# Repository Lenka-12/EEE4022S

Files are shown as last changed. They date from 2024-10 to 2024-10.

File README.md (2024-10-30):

# Audio Digitisation System 🎵



A high-performance audio digitization system built around the STM32F7 microcontroller, featuring dual Delta-Sigma ADCs (PCM1808 and ADAU1978) and an integrated ADC for comprehensive audio capture.

## 🎯 Overview

This project implements a complete audio digitization pipeline that captures audio data through multiple ADCs and transmits it to a PC for MATLAB-based analysis.

## 🔧 Hardware Components

### STM32F7 Nucleo Board
- Main processing unit
- Handles ADC interfacing and USB communication

### PCM1808 Delta-Sigma ADC ([Buy](https://www.aliexpress.com/item/32777376004.html))
- Stereo Audio ADC configuration
- Input: Bottom port MEMS microphone from DEVKIT-MEMS-001
- Signal conditioning via AD828 op-amp module ([AD828 Module Source](https://www.robotics.org.za/AD828A))
- I2S interface via SAI1 Block B
- 48 kHz sampling rate
- DMA circular mode operation

### Integrated ADC
- Input: Nucleo board pin A3
- Signal from top port MEMS microphone (DEVKIT-MEMS-001)
- Signal conditioning via BOB-09816 ([SparkFun BOB-09816](https://www.sparkfun.com/products/9816))
- Timer-triggered operation
- Circular DMA mode

### ADAU1978 Delta-Sigma ADC
- Integrated via [STEVAL-STWINMAV1](https://www.st.com/en/evaluation-tools/steval-stwinmav1.html) module
- TDM4 protocol through SAI1 Block A
- 24-bit resolution at 48 kHz
- DMA circular mode operation

> **Important Note**: When configuring SAI for TDM:
> - Clock strobing must be set to rising edge
> - Frame Synchro offset must be set before the First Bit

## 🔌 Communication

### USB Interface
- Protocol: USB Full Speed (FS) CDC
- Data transmission triggered by user button
- ADC activation controlled via Python script commands

## 💡 Status Indicators

| LED  | Function |
|---|---|
| LD1  | Integrated ADC active |
| LD2  | PCM1808 active |
| LD3  | ADAU1978 active |

## 🛠️ Hardware Sources

### Microphones
- [DEVKIT-MEMS-001](https://www.sameskydevices.com/product/audio/microphones/development-kits/devkit-mems-001)
  - Bottom port MEMS mic → PCM1808
  - Top port MEMS mic → Integrated ADC

### Signal Conditioning
- PCM1808: [AD828 Op-amp Module](https://www.robotics.org.za/AD828A)
- Integrated ADC: [BOB-09816](https://www.sparkfun.com/products/9816)

### ADC Modules
- [PCM1808 Stereo Delta-Sigma ADC](https://www.aliexpress.com/item/32777376004.html)
- [STEVAL-STWINMAV1](https://www.st.com/en/evaluation-tools/steval-stwinmav1.html) (ADAU1978)
- STM32F7 Integrated ADC

## 📝 PCB Documentation

The repository includes:
- STEVAL-STWINMAV1 module adapter designs
- Audio Digitisation Hardware based on PCM1862 (production pending)
- 
## 📊 Data Analysis

MATLAB scripts are provided for processing the captured audio data. See the `/Processing` directory for analysis tools.

## 🤝 Contributing

Contributions are welcome! Please read our [Contributing Guide](CONTRIBUTING.md) for details on our code of conduct and the process for submitting pull requests.

## 📄 License

This project is licensed under the MIT License - see the [LICENSE](LICENSE) file for details.

## ✨ Acknowledgments

- STMicroelectronics for the STEVAL-STWINMAV1 reference design
- Same Sky for DEVKIT-MEMS-001
- SparkFun Electronics for BOB-09816
- Contributors and testers

---
*For technical questions and support, please open an issue in the repository.*

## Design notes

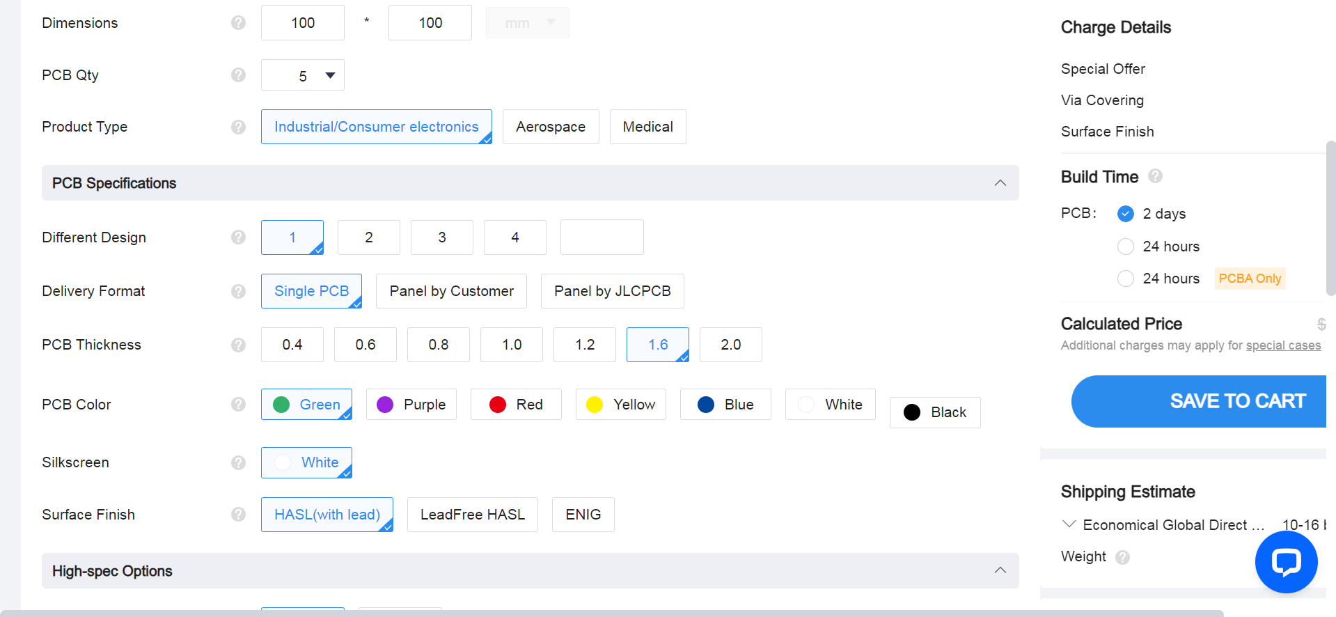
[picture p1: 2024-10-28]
PCB/Audio_Digitizer/Manufucturing/Images/Basic_PCB_Specs.png

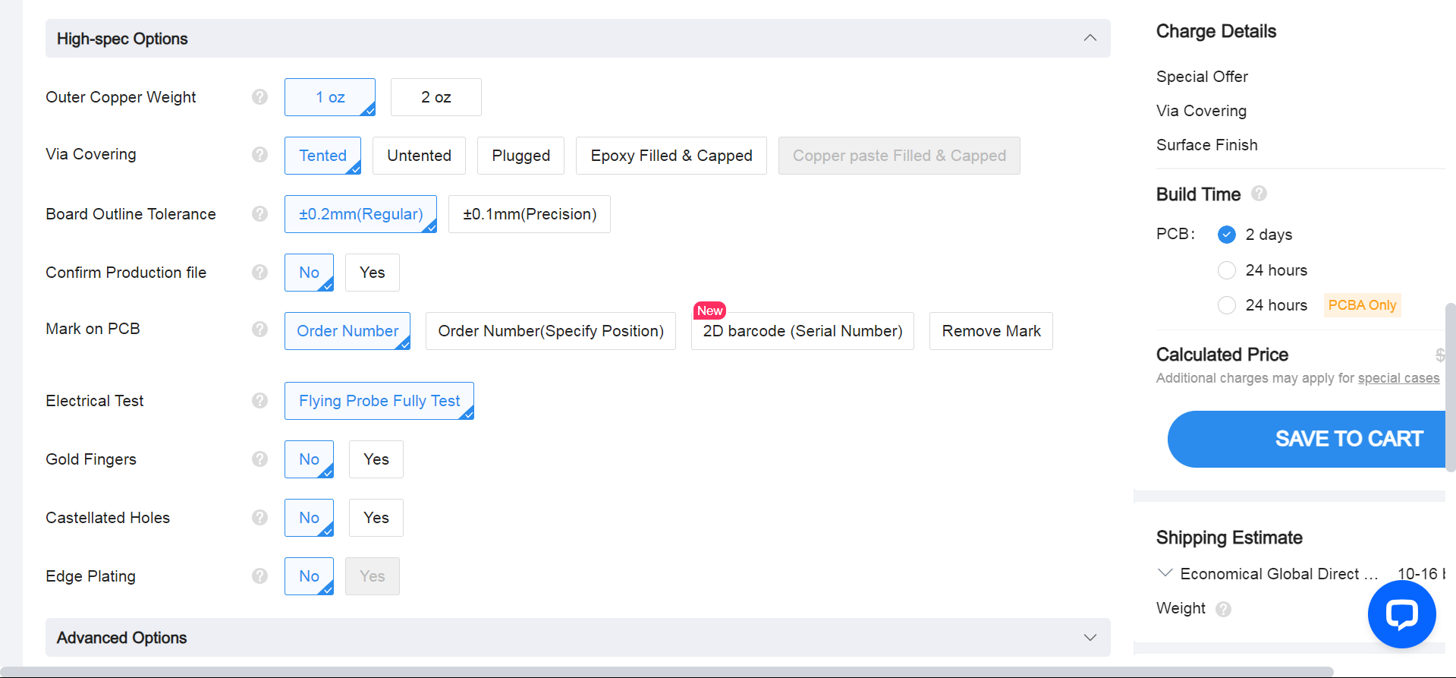
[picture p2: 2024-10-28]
PCB/Audio_Digitizer/Manufucturing/Images/PCB_High_Specs.png

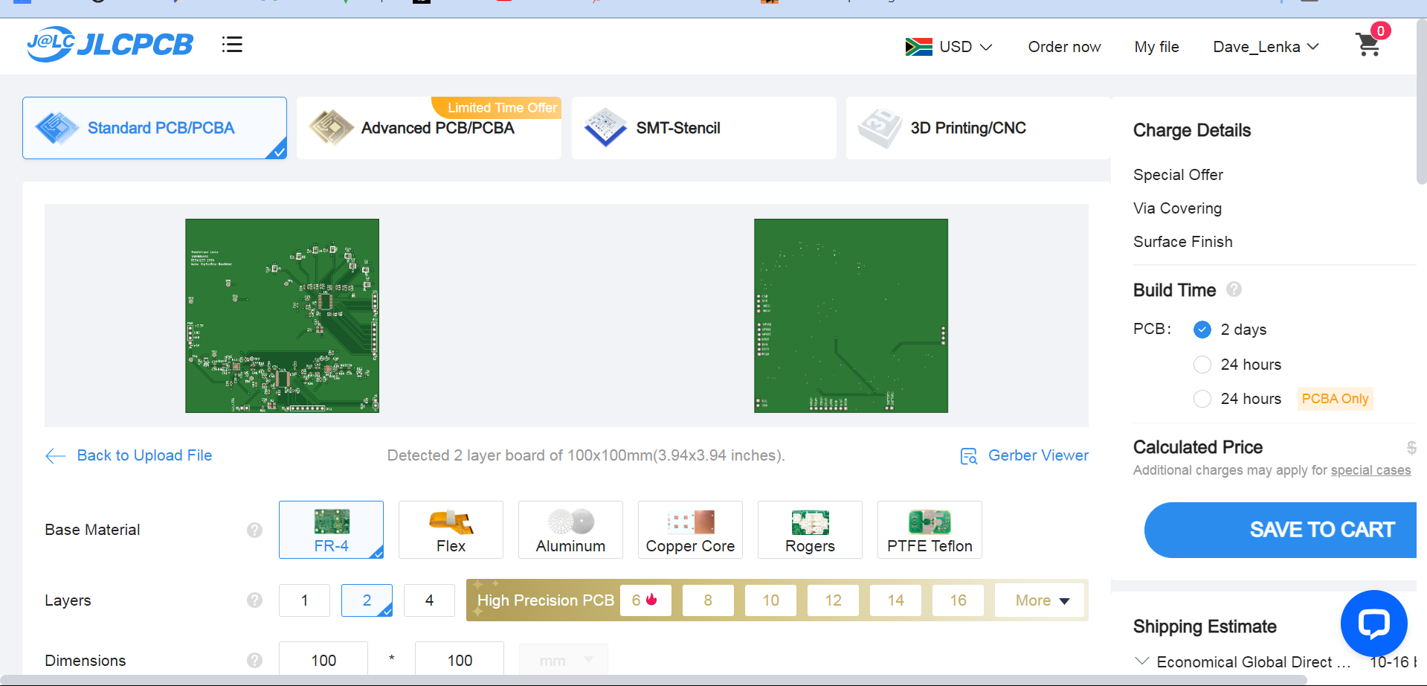
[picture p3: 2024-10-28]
PCB/Audio_Digitizer/Manufucturing/Images/PCB_Dimensions.png

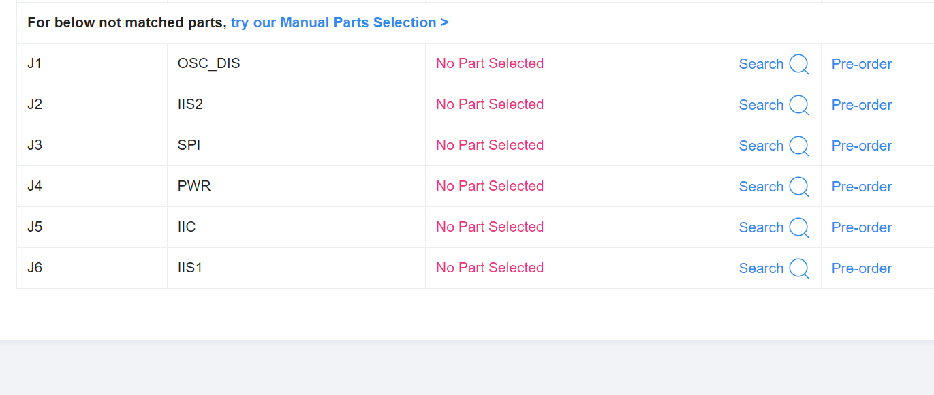
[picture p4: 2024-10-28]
PCB/Audio_Digitizer/Manufucturing/Images/Do_Not_Populate.png

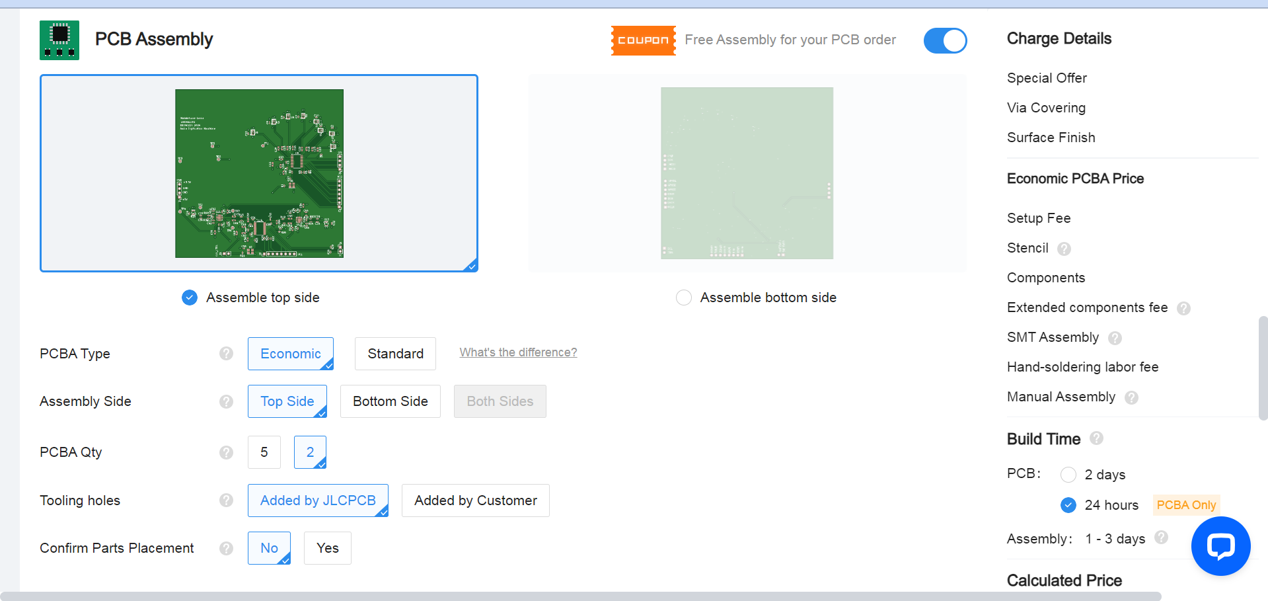
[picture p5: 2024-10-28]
PCB/Audio_Digitizer/Manufucturing/Images/PCBA_QTY.png

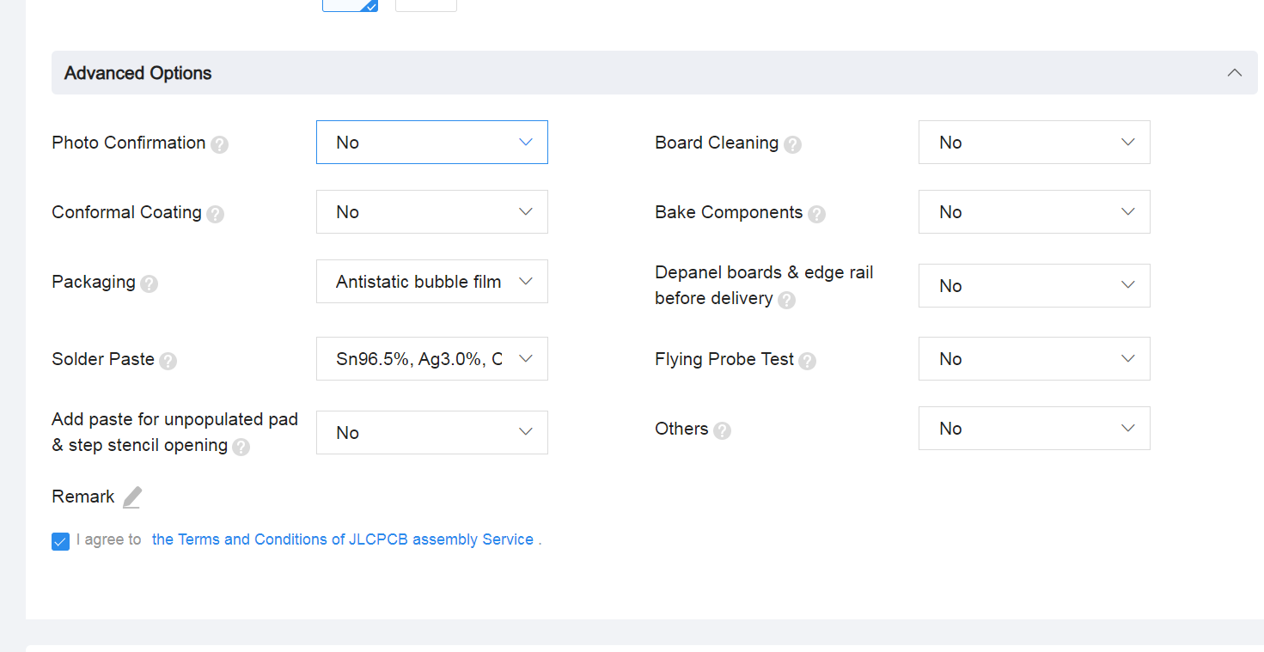
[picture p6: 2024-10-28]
PCB/Audio_Digitizer/Manufucturing/Images/PCBA_Advanced_Options.png

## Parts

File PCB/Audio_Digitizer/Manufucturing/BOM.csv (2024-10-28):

Reference | Value | Footprint | DNP | LCSC
C1,C2,C3,C4,C5,C6,C7,C9,C10,C12,C17,C24,C25,C26,C27,C28,C29,C30,C31,C32,C33,C56,C57,C58 | 100n | Capacitor_SMD:C_0402_1005Metric
C8,C11,C15,C16,C18,C19,C20,C21,C22,C23,C34,C35,C46,C47,C48,C52,C59,C60 | 10u | Capacitor_SMD:C_0603_1608Metric
C13,C14,C61,C62 | 2.2u | Capacitor_SMD:C_0603_1608Metric
C36,C37,C38,C39 | 4.7u | Capacitor_SMD:C_0402_1005Metric
C40,C43 | 100p | Capacitor_SMD:C_0402_1005Metric
C41,C42,C44,C45 | 47p | Capacitor_SMD:C_0402_1005Metric
C49,C51,C53,C55 | 220p | Capacitor_SMD:C_0402_1005Metric
C50,C54 | 6.8n | Capacitor_SMD:C_0603_1608Metric
J1 | OSC_DIS | Connector_PinHeader_2.54mm:PinHeader_1x02_P2.54mm_Vertical | DNP
J2 | IIS2 | Connector_PinHeader_2.54mm:PinHeader_1x07_P2.54mm_Vertical | DNP
J3 | SPI | Connector_PinHeader_2.54mm:PinHeader_1x04_P2.54mm_Vertical | DNP
J4 | PWR | Connector_PinHeader_2.54mm:PinHeader_1x04_P2.54mm_Vertical | DNP
J5 | IIC | Connector_PinHeader_2.54mm:PinHeader_1x02_P2.54mm_Vertical | DNP
J6 | IIS1 | Connector_PinHeader_2.54mm:PinHeader_1x08_P2.54mm_Vertical | DNP
R1,R5,R21,R25,R26 | 10k | Resistor_SMD:R_0402_1005Metric
R2,R3,R4,R6,R22,R23,R24,R27 | 22 | Resistor_SMD:R_0402_1005Metric
R7,R8 | 1k | Resistor_SMD:R_0603_1608Metric
R9,R10,R13,R14 | 1.2k | Resistor_SMD:R_0402_1005Metric
R11,R12,R15,R16 | 33k | Resistor_SMD:R_0402_1005Metric
R17,R18,R19,R20 | 47 | Resistor_SMD:R_0402_1005Metric
R28,R29 | 4.7k | Resistor_SMD:R_0402_1005Metric
TP1,TP2,TP3,TP4,TP5,TP6,TP7,TP8 | TestPoint | TestPoint:TestPoint_Pad_D1.5mm
U1,U2,U3,U4,U5,U6,U7,U8 | WMM7027ABSN0-4_TR | footprints:MIC-SMD_4P-L2.8-W1.9_MSM38A2718Z9BM3 |  | C2931972
U9,U14 | PCM1862DBTR | Package_SO:TSSOP-30_4.4x7.8mm_P0.5mm
U10,U12 | ZTS6216 | footprints:MIC-SMD_4P-L2.8-W1.9-P1.84-TL |  | C481302
U11,U13 | ADA4945-1ACPZ-R7 | Package_CSP:LFCSP-16-1EP_3x3mm_P0.5mm_EP1.6x1.6mm |  | C560261
X1,X2 | ASCO | Crystal:Crystal_SMD_3225-4Pin_3.2x2.5mm

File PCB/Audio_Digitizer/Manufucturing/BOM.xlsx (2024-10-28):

Designator | Comment | Footprint | JLCPCB Part #
C1,C2,C3,C4,C5,C6,C7,C9,C10,C12,C17,C24,C25,C26,C27,C28,C29,C30,C31,C32,C33,C56,C57,C58 | 100n | Capacitor_SMD:C_0402_1005Metric | C1525
C8,C11,C15,C16,C18,C19,C20,C21,C22,C23,C34,C35,C46,C47,C48,C52,C59,C60 | 10u | Capacitor_SMD:C_0603_1608Metric | C19702
C13,C14,C61,C62 | 2.2u | Capacitor_SMD:C_0603_1608Metric | C23630
C36,C37,C38,C39 | 4.7u | Capacitor_SMD:C_0402_1005Metric | C23733
C40,C43 | 100p | Capacitor_SMD:C_0402_1005Metric | C1546
C41,C42,C44,C45 | 47p | Capacitor_SMD:C_0402_1005Metric | C1567
C49,C51,C53,C55 | 220p | Capacitor_SMD:C_0402_1005Metric | C1530
C50,C54 | 6.8n | Capacitor_SMD:C_0603_1608Metric | C1631
J1 | OSC_DIS
J2 | IIS2
J3 | SPI
J4 | PWR
J5 | IIC
J6 | IIS1
R1,R5,R21,R25,R26 | 10k | Resistor_SMD:R_0402_1005Metric | C25744
R2,R3,R4,R6,R22,R23,R24,R27 | 22 | Resistor_SMD:R_0402_1005Metric | C25092
R7,R8 | 1k | Resistor_SMD:R_0603_1608Metric | C21190
R9,R10,R13,R14 | 1.2k | Resistor_SMD:R_0402_1005Metric | C25862
R11,R12,R15,R16 | 33k | Resistor_SMD:R_0402_1005Metric | C25779
R17,R18,R19,R20 | 47 | Resistor_SMD:R_0402_1005Metric | C25118
R28,R29 | 4.7k | Resistor_SMD:R_0402_1005Metric | C25900
U1,U2,U3,U4,U5,U6,U7,U8 | WMM7027ABSN0-4_TR | LGA-4(1.9x2.8) | C2931972
U9,U14 | PCM1862DBTR | TSSOP-30-4.4mm | C544647
U10,U12 | ZTS6216 | SMD-4P, 1.9x2.8mm | C481302
U11,U13 | ADA4945-1ACPZ-R7 | LFCSP-16(3x3) | C560261
X1,X2 | ASCO | SMD3225-4P | C2831388

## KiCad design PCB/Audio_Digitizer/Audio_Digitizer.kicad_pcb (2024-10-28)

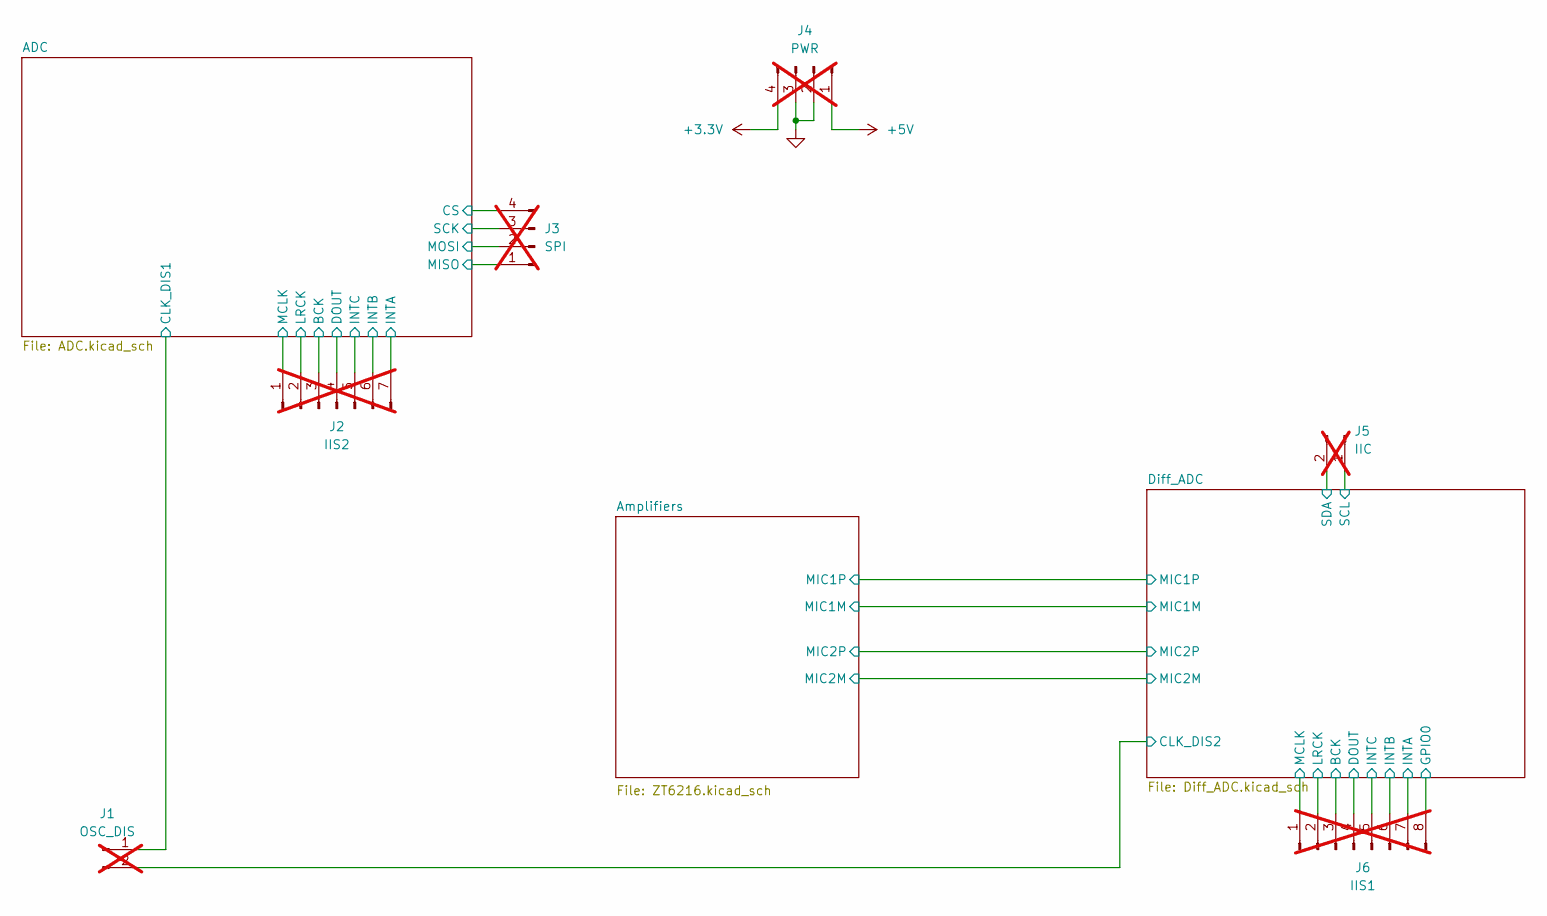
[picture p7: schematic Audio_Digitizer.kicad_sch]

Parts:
J1: OSC_DIS; PinHeader_1x02_P2.54mm_Vertical; not fitted
J2: IIS2; PinHeader_1x07_P2.54mm_Vertical; not fitted
J3: SPI; PinHeader_1x04_P2.54mm_Vertical; not fitted
J4: PWR; PinHeader_1x04_P2.54mm_Vertical; not fitted
J5: IIC; PinHeader_1x02_P2.54mm_Vertical; not fitted
J6: IIS1; PinHeader_1x08_P2.54mm_Vertical; not fitted

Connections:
+3.3V: J4.4; also elsewhere on the board
+5V: J4.1; also elsewhere on the board
/ADC/BCK: J2.3; also elsewhere on the board
/ADC/CLK_DIS1: J1.1; also elsewhere on the board
/ADC/CS: J3.4; also elsewhere on the board
/ADC/DOUT: J2.4; also elsewhere on the board
/ADC/INTA: J2.7; also elsewhere on the board
/ADC/INTB: J2.6; also elsewhere on the board
/ADC/INTC: J2.5; also elsewhere on the board
/ADC/LRCK: J2.2; also elsewhere on the board
/ADC/MCLK: J2.1; also elsewhere on the board
/ADC/MISO: J3.1; also elsewhere on the board
/ADC/MOSI: J3.2; also elsewhere on the board
/ADC/SCK: J3.3; also elsewhere on the board
/Diff_ADC/BCK: J6.3; also elsewhere on the board
/Diff_ADC/CLK_DIS2: J1.2; also elsewhere on the board
/Diff_ADC/DOUT: J6.4; also elsewhere on the board
/Diff_ADC/GPIO0: J6.8; also elsewhere on the board
/Diff_ADC/INTA: J6.7; also elsewhere on the board
/Diff_ADC/INTB: J6.6; also elsewhere on the board
/Diff_ADC/INTC: J6.5; also elsewhere on the board
/Diff_ADC/LRCK: J6.2; also elsewhere on the board
/Diff_ADC/MCLK: J6.1; also elsewhere on the board
/Diff_ADC/SCL: J5.1; also elsewhere on the board
/Diff_ADC/SDA: J5.2; also elsewhere on the board
GND: J4.2, J4.3; also elsewhere on the board

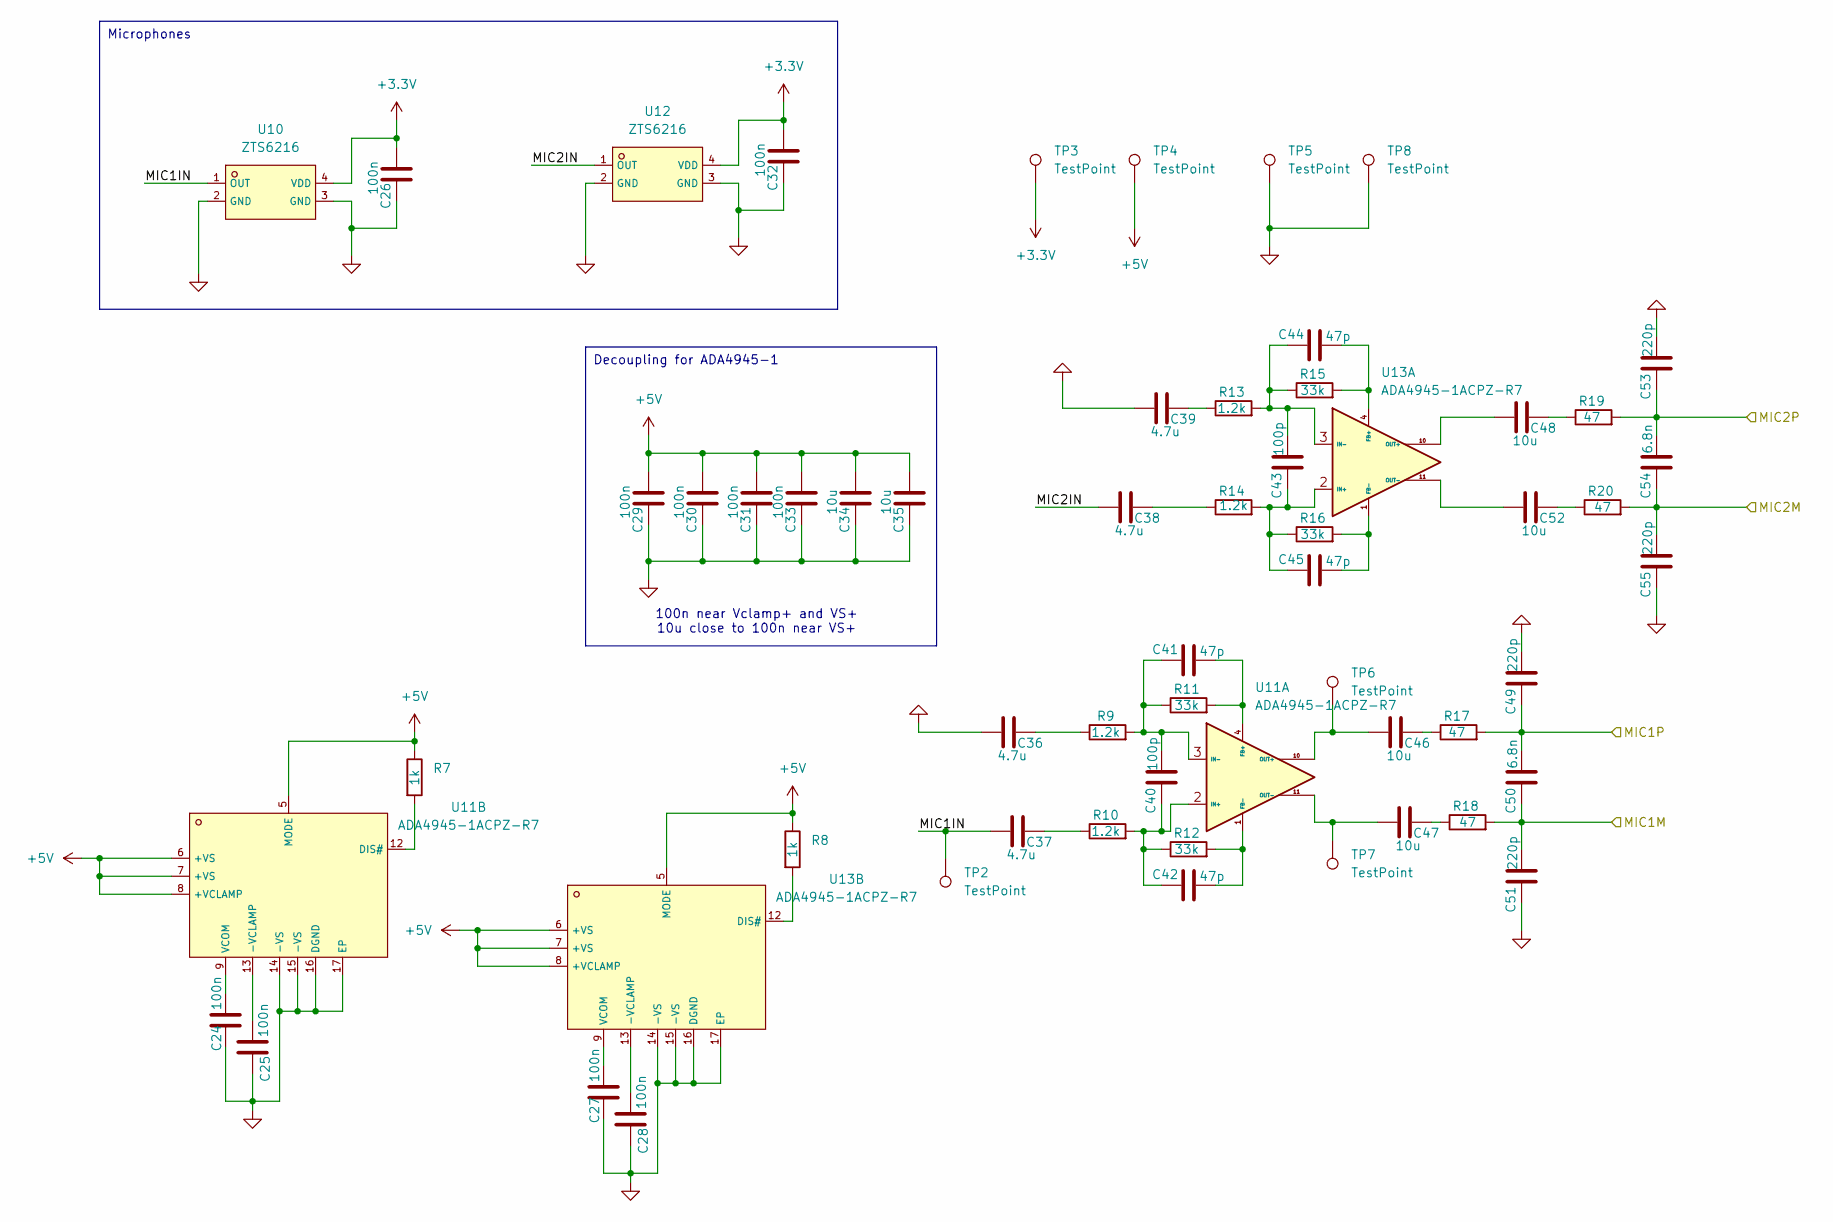
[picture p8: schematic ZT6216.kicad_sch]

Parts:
C24, C25, C26, C27, C28, C29, C30, C31, C32, C33: 100n; C_0402_1005Metric
C34, C35, C46, C47, C48, C52: 10u; C_0603_1608Metric
C36, C37, C38, C39: 4.7u; C_0402_1005Metric
C40, C43: 100p; C_0402_1005Metric
C41, C42, C44, C45: 47p; C_0402_1005Metric
C49, C51, C53, C55: 220p; C_0402_1005Metric
C50, C54: 6.8n; C_0603_1608Metric
R7, R8: 1k; R_0603_1608Metric
R9, R10, R13, R14: 1.2k; R_0402_1005Metric
R11, R12, R15, R16: 33k; R_0402_1005Metric
R17, R18, R19, R20: 47; R_0402_1005Metric
TP2, TP3, TP4, TP5, TP6, TP7, TP8: TestPoint; TestPoint_Pad_D1.5mm
U10, U12: ZTS6216; MIC-SMD_4P-L2.8-W1.9-P1.84-TL; LCSC C481302
U11, U13: ADA4945-1ACPZ-R7; LFCSP-16-1EP_3x3mm_P0.5mm_EP1.6x1.6mm; LCSC C560261

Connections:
+3.3V: C26.1, C32.1, TP3.1, U10.4 (VDD), U12.4 (VDD); also elsewhere on the board
+5V: C29.1, C30.1, C31.1, C33.1, C34.1, C35.1, R7.1, R8.1, TP4.1, U11.5 (MODE), U11.6 (+VS), U11.7 (+VS), U11.8 (+VCLAMP), U13.5 (MODE), U13.6 (+VS), U13.7 (+VS), U13.8 (+VCLAMP); also elsewhere on the board
/Amplifiers/MIC1IN: C37.1, TP2.1, U10.1 (OUT)
/Amplifiers/MIC1M: C50.1, C51.2, R18.2; also elsewhere on the board
/Amplifiers/MIC1P: C49.1, C50.2, R17.2; also elsewhere on the board
/Amplifiers/MIC2IN: C38.1, U12.1 (OUT)
/Amplifiers/MIC2M: C54.1, C55.2, R20.2; also elsewhere on the board
/Amplifiers/MIC2P: C53.1, C54.2, R19.2; also elsewhere on the board
GND: C24.1, C25.1, C26.2, C27.1, C28.1, C29.2, C30.2, C31.2, C32.2, C33.2, C34.2, C35.2, C36.1, C39.1, C49.2, C51.1, C53.2, C55.1, TP5.1, TP8.1, U10.2 (GND), U10.3 (GND), U11.14 (-VS), U11.15 (-VS), U11.16 (DGND), U11.17 (EP), U12.2 (GND), U12.3 (GND), U13.14 (-VS), U13.15 (-VS), U13.16 (DGND), U13.17 (EP); also elsewhere on the board
unnamed: C36.2, R9.1
unnamed: C37.2, R10.1
unnamed: C38.2, R14.1
unnamed: C39.2, R13.1
unnamed: C46.2, R17.1
unnamed: C47.2, R18.1
unnamed: C48.2, R19.1
unnamed: C52.2, R20.1
unnamed: C41.2, R11.2, U11.4 (FB+)
unnamed: C42.2, R12.2, U11.1 (FB-)
unnamed: C40.1, C42.1, R10.2, R12.1, U11.2 (IN+)
unnamed: C40.2, C41.1, R9.2, R11.1, U11.3 (IN-)
unnamed: C46.1, TP6.1, U11.10 (OUT+)
unnamed: C47.1, TP7.1, U11.11 (OUT-)
unnamed: C25.2, U11.13 (-VCLAMP)
unnamed: R7.2, U11.12 (DIS#)
unnamed: C24.2, U11.9 (VCOM)
unnamed: C44.2, R15.2, U13.4 (FB+)
unnamed: C45.2, R16.2, U13.1 (FB-)
unnamed: C43.1, C45.1, R14.2, R16.1, U13.2 (IN+)
unnamed: C43.2, C44.1, R13.2, R15.1, U13.3 (IN-)
unnamed: C48.1, U13.10 (OUT+)
unnamed: C52.1, U13.11 (OUT-)
unnamed: C28.2, U13.13 (-VCLAMP)
unnamed: R8.2, U13.12 (DIS#)
unnamed: C27.2, U13.9 (VCOM)

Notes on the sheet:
Decoupling for ADA4945-1
Microphones
100n near Vclamp+ and VS+ 10u close to 100n near VS+

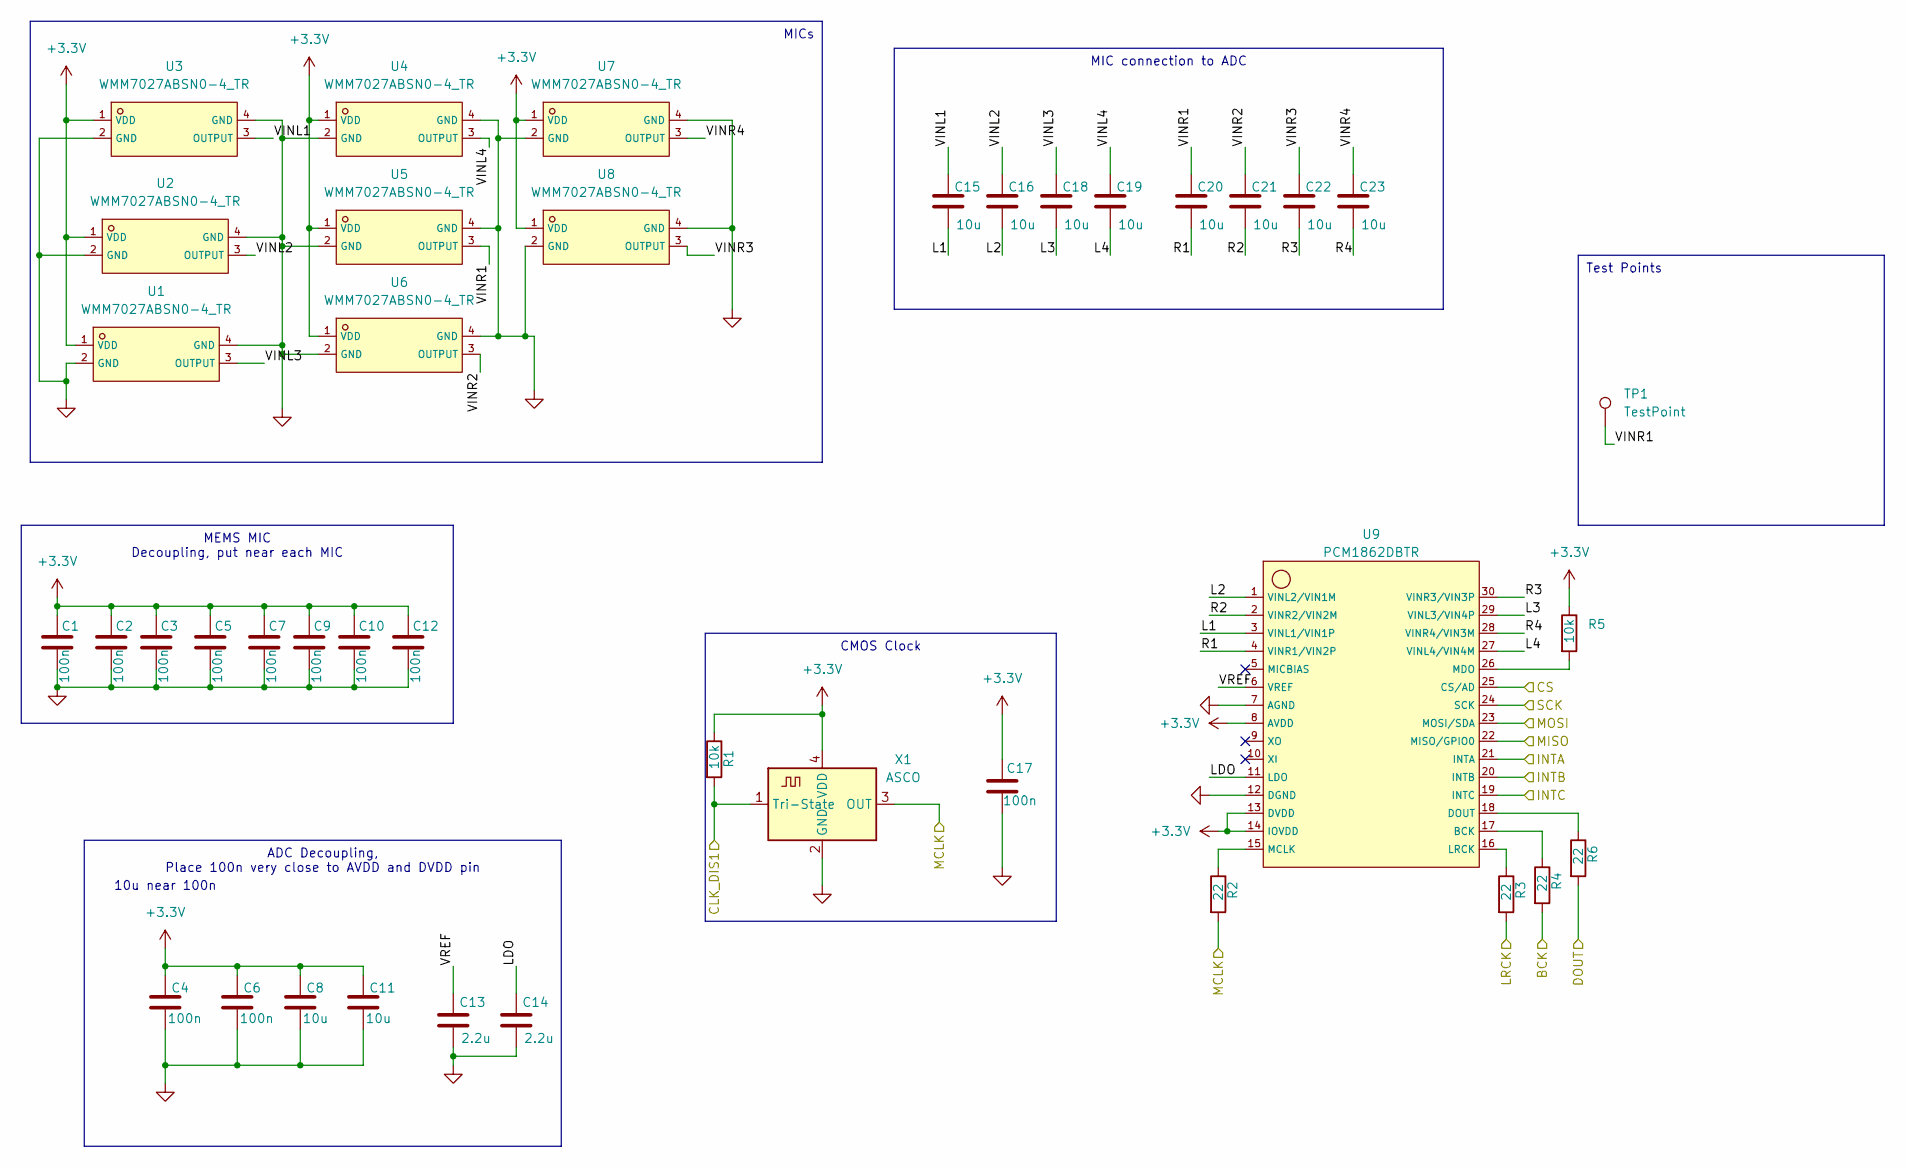
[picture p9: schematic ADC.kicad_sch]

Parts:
C1, C2, C3, C4, C5, C6, C7, C9, C10, C12, C17: 100n; C_0402_1005Metric
C8, C11, C15, C16, C18, C19, C20, C21, C22, C23: 10u; C_0603_1608Metric
C13, C14: 2.2u; C_0603_1608Metric
R1, R5: 10k; R_0402_1005Metric
R2, R3, R4, R6: 22; R_0402_1005Metric
TP1: TestPoint; TestPoint_Pad_D1.5mm
U1, U2, U3, U4, U5, U6, U7, U8: WMM7027ABSN0-4_TR; MIC-SMD_4P-L2.8-W1.9_MSM38A2718Z9BM3; LCSC C2931972
U9: PCM1862DBTR; TSSOP-30_4.4x7.8mm_P0.5mm
X1: ASCO; Crystal_SMD_3225-4Pin_3.2x2.5mm

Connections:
+3.3V: C1.1, C2.1, C3.1, C4.1, C5.1, C6.1, C7.1, C8.1, C9.1, C10.1, C11.1, C12.1, C17.1, R1.1, R5.1, U1.1 (VDD), U2.1 (VDD), U3.1 (VDD), U4.1 (VDD), U5.1 (VDD), U6.1 (VDD), U7.1 (VDD), U8.1 (VDD), U9.8 (AVDD), U9.13 (DVDD), U9.14 (IOVDD), X1.4 (VDD); also elsewhere on the board
/ADC/BCK: R4.2; also elsewhere on the board
/ADC/CLK_DIS1: R1.2, X1.1 (Tri-State); also elsewhere on the board
/ADC/CS: U9.25 (CS/AD); also elsewhere on the board
/ADC/DOUT: R6.2; also elsewhere on the board
/ADC/INTA: U9.21 (INTA); also elsewhere on the board
/ADC/INTB: U9.20 (INTB); also elsewhere on the board
/ADC/INTC: U9.19 (INTC); also elsewhere on the board
/ADC/L1: C15.2, U9.3 (VINL1/VIN1P)
/ADC/L2: C16.2, U9.1 (VINL2/VIN1M)
/ADC/L3: C18.2, U9.29 (VINL3/VIN4P)
/ADC/L4: C19.2, U9.27 (VINL4/VIN4M)
/ADC/LDO: C14.1, U9.11 (LDO)
/ADC/LRCK: R3.2; also elsewhere on the board
/ADC/MCLK: R2.2, X1.3 (OUT); also elsewhere on the board
/ADC/MISO: U9.22 (MISO/GPIO0); also elsewhere on the board
/ADC/MOSI: U9.23 (MOSI/SDA); also elsewhere on the board
/ADC/R1: C20.2, U9.4 (VINR1/VIN2P)
/ADC/R2: C21.2, U9.2 (VINR2/VIN2M)
/ADC/R3: C22.2, U9.30 (VINR3/VIN3P)
/ADC/R4: C23.2, U9.28 (VINR4/VIN3M)
/ADC/SCK: U9.24 (SCK); also elsewhere on the board
/ADC/VINL1: C15.1, U3.3 (OUTPUT)
/ADC/VINL2: C16.1, U2.3 (OUTPUT)
/ADC/VINL3: C18.1, U1.3 (OUTPUT)
/ADC/VINL4: C19.1, U4.3 (OUTPUT)
/ADC/VINR1: C20.1, TP1.1, U5.3 (OUTPUT)
/ADC/VINR2: C21.1, U6.3 (OUTPUT)
/ADC/VINR3: C22.1, U8.3 (OUTPUT)
/ADC/VINR4: C23.1, U7.3 (OUTPUT)
/ADC/VREF: C13.1, U9.6 (VREF)
GND: C1.2, C2.2, C3.2, C4.2, C5.2, C6.2, C7.2, C8.2, C9.2, C10.2, C11.2, C12.2, C13.2, C14.2, C17.2, U1.2 (GND), U1.4 (GND), U2.2 (GND), U2.4 (GND), U3.2 (GND), U3.4 (GND), U4.2 (GND), U4.4 (GND), U5.2 (GND), U5.4 (GND), U6.2 (GND), U6.4 (GND), U7.2 (GND), U7.4 (GND), U8.2 (GND), U8.4 (GND), U9.7 (AGND), U9.12 (DGND), X1.2 (GND); also elsewhere on the board
unnamed: R4.1, U9.17 (BCK)
unnamed: R6.1, U9.18 (DOUT)
unnamed: R3.1, U9.16 (LRCK)
unnamed: R2.1, U9.15 (MCLK)
unnamed: R5.2, U9.26 (MDO)

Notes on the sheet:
CMOS Clock
MICs
Test Points
ADC Decoupling, Place 100n very close to AVDD and DVDD pin
MEMS MIC Decoupling, put near each MIC
MIC connection to ADC
10u near 100n

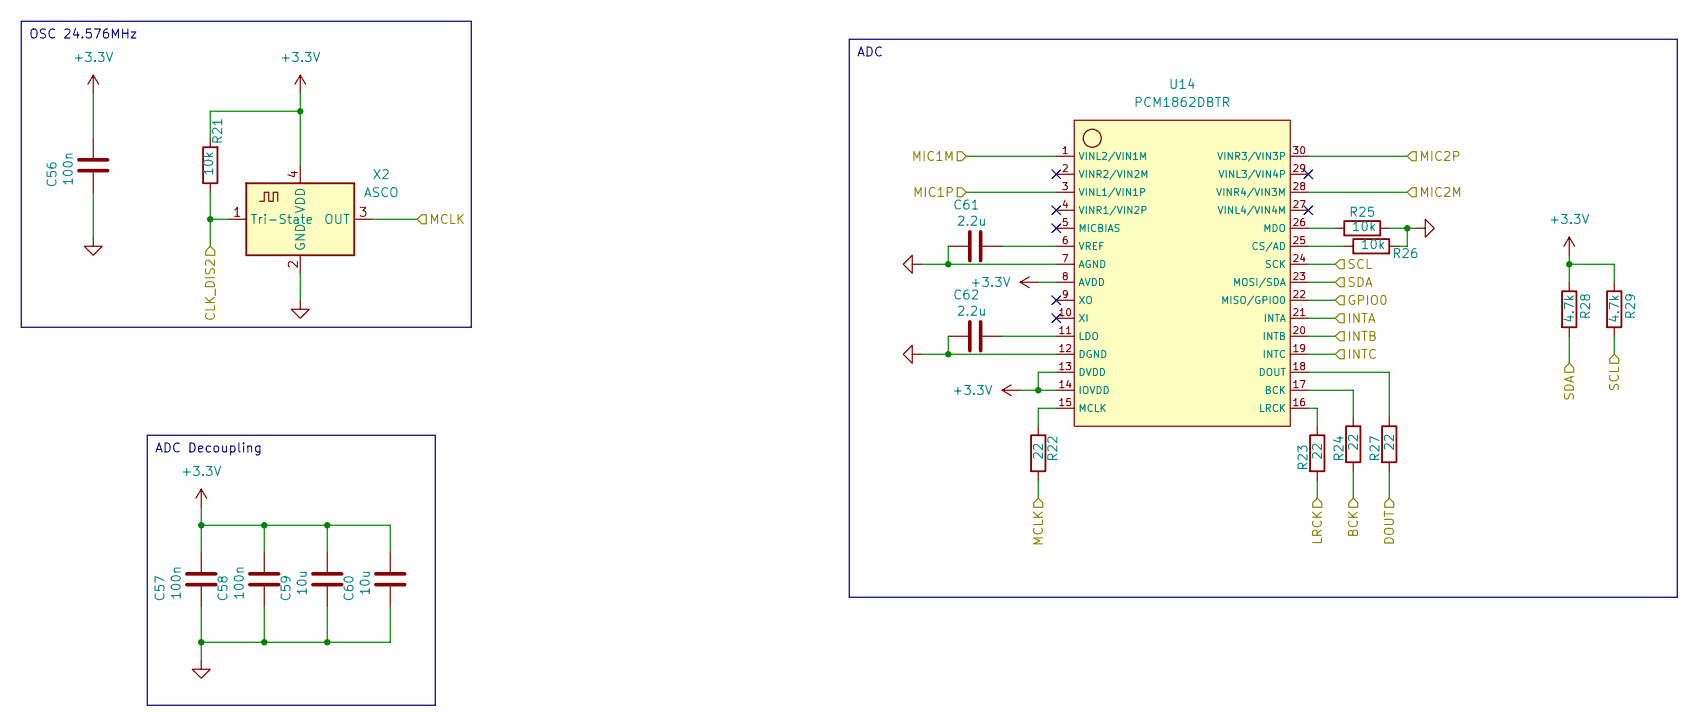
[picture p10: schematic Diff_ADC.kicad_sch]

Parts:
C56, C57, C58: 100n; C_0402_1005Metric
C59, C60: 10u; C_0603_1608Metric
C61, C62: 2.2u; C_0603_1608Metric
R21, R25, R26: 10k; R_0402_1005Metric
R22, R23, R24, R27: 22; R_0402_1005Metric
R28, R29: 4.7k; R_0402_1005Metric
U14: PCM1862DBTR; TSSOP-30_4.4x7.8mm_P0.5mm
X2: ASCO; Crystal_SMD_3225-4Pin_3.2x2.5mm

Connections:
+3.3V: C56.2, C57.2, C58.2, C59.2, C60.2, R21.2, R28.1, R29.1, U14.8 (AVDD), U14.13 (DVDD), U14.14 (IOVDD), X2.4 (VDD); also elsewhere on the board
/Amplifiers/MIC1M: U14.1 (VINL2/VIN1M); also elsewhere on the board
/Amplifiers/MIC1P: U14.3 (VINL1/VIN1P); also elsewhere on the board
/Amplifiers/MIC2M: U14.28 (VINR4/VIN3M); also elsewhere on the board
/Amplifiers/MIC2P: U14.30 (VINR3/VIN3P); also elsewhere on the board
/Diff_ADC/BCK: R24.2; also elsewhere on the board
/Diff_ADC/CLK_DIS2: R21.1, X2.1 (Tri-State); also elsewhere on the board
/Diff_ADC/DOUT: R27.2; also elsewhere on the board
/Diff_ADC/GPIO0: U14.22 (MISO/GPIO0); also elsewhere on the board
/Diff_ADC/INTA: U14.21 (INTA); also elsewhere on the board
/Diff_ADC/INTB: U14.20 (INTB); also elsewhere on the board
/Diff_ADC/INTC: U14.19 (INTC); also elsewhere on the board
/Diff_ADC/LRCK: R23.2; also elsewhere on the board
/Diff_ADC/MCLK: R22.2, X2.3 (OUT); also elsewhere on the board
/Diff_ADC/SCL: R29.2, U14.24 (SCK); also elsewhere on the board
/Diff_ADC/SDA: R28.2, U14.23 (MOSI/SDA); also elsewhere on the board
GND: C56.1, C57.1, C58.1, C59.1, C60.1, C61.1, C62.1, R25.2, R26.2, U14.7 (AGND), U14.12 (DGND), X2.2 (GND); also elsewhere on the board
unnamed: R24.1, U14.17 (BCK)
unnamed: R26.1, U14.25 (CS/AD)
unnamed: R27.1, U14.18 (DOUT)
unnamed: C62.2, U14.11 (LDO)
unnamed: R23.1, U14.16 (LRCK)
unnamed: R22.1, U14.15 (MCLK)
unnamed: R25.1, U14.26 (MDO)
unnamed: C61.2, U14.6 (VREF)

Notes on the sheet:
OSC 24.576MHz
ADC Decoupling
ADC

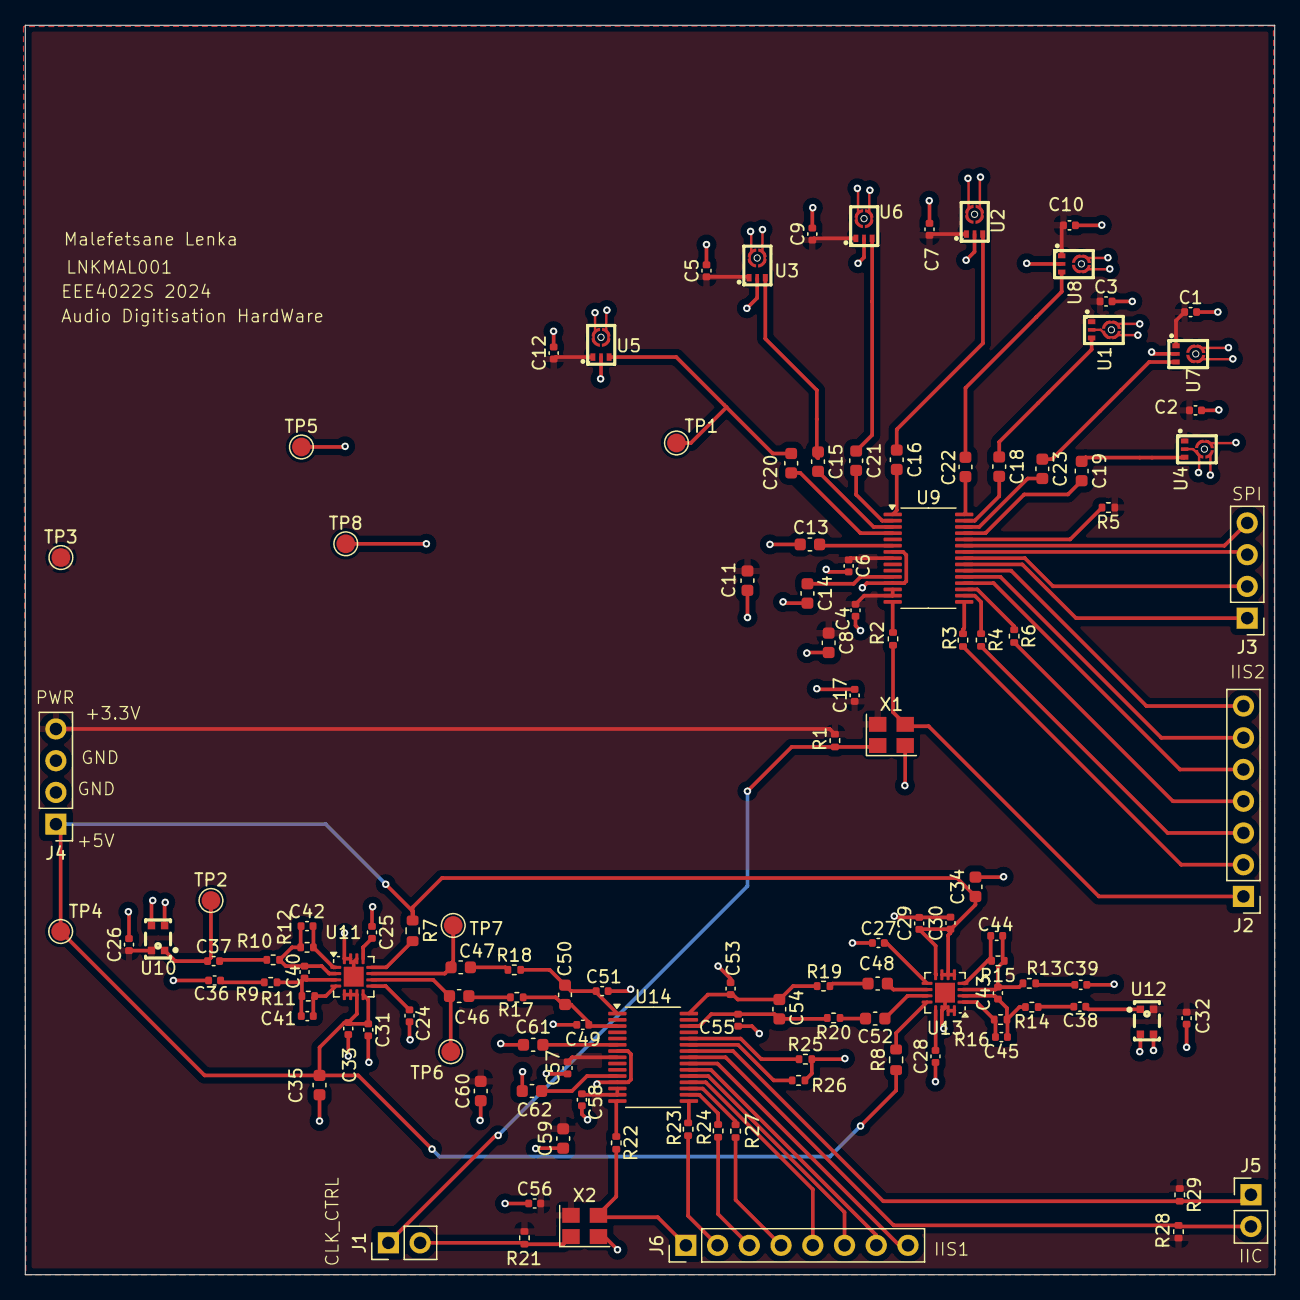
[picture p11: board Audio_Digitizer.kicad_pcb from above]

Board: 2 copper layers, 100.0 x 100.0 mm, 121 parts (0 on the bottom side), 89 nets.

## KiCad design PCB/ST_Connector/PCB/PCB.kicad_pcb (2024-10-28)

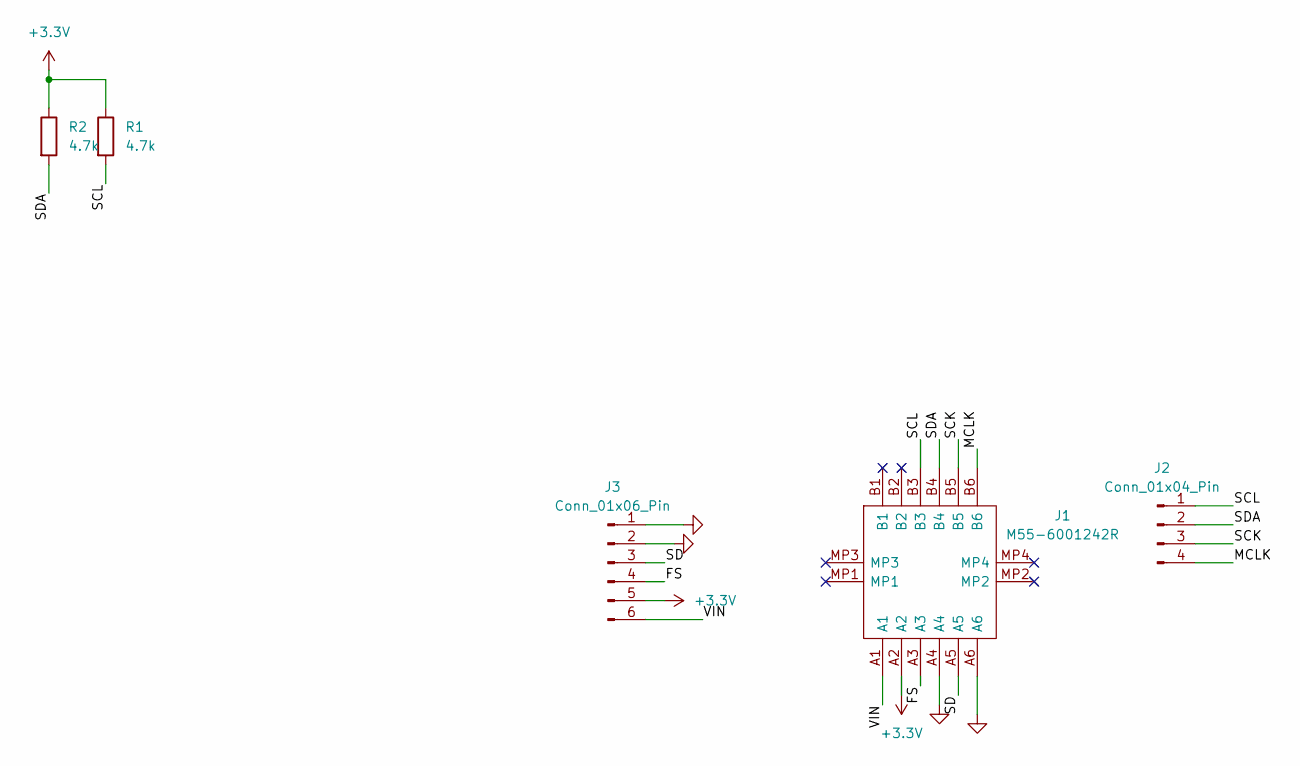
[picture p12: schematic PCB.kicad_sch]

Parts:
J1: M55-6001242R; M556001242R; Manufacturer_Part_Number M55-6001242R; Mouser Part Number 855-M55-6001242R
J2: Conn_01x04_Pin; PinHeader_1x04_P2.54mm_Vertical
J3: Conn_01x06_Pin; PinHeader_1x06_P2.54mm_Vertical
R1, R2: 4.7k; R_Axial_DIN0204_L3.6mm_D1.6mm_P5.08mm_Horizontal

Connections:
+3.3V: J1.A2, J3.5, R1.1, R2.1
/FS: J1.A3, J3.4
/MCLK: J1.B6, J2.4
/SCK: J1.B5, J2.3
/SCL: J1.B3, J2.1, R1.2
/SD: J1.A5, J3.3
/SDA: J1.B4, J2.2, R2.2
/VIN: J1.A1, J3.6
GND: J1.A4, J1.A6, J3.1, J3.2

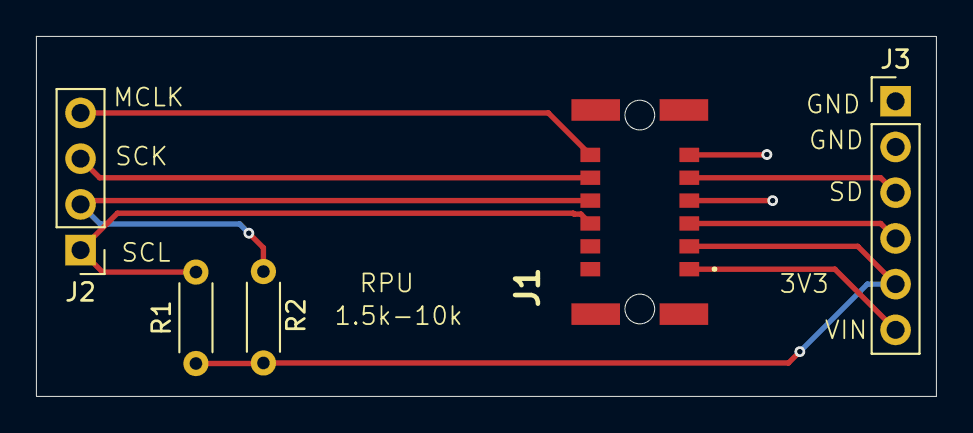
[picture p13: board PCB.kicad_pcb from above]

Board: 2 copper layers, 50.0 x 20.0 mm, 5 parts (0 on the bottom side), 9 nets.

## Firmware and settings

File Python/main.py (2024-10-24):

import serial
import time
import argparse

def serial_port_init(port, baud_rate, time_out):
    # initialise a serial port
    try:
        ser = serial.Serial(port, baud_rate, timeout=time_out) 
        
        time.sleep(2)  # Give some time for the connection to be established

        print(f"Serial port {port} initialized successfully.")
        return ser
    
    except serial.SerialException as e:
        print(f"Serial initialisation error: {e}")
        return None

    except Exception as e:
        print(f"An unexpected error occurred: {e}")
        return None
def read_from_serial(ser, arr_size):
    received_data = bytearray()
    while len(received_data) < arr_size:
        # Read remaining bytes needed
        remaining_bytes = arr_size - len(received_data)
        data = ser.read(remaining_bytes)
        if data:
            received_data.extend(data)
    return received_data
def write_stereo(data_buffer):
    # File handles for each channel
    files = [
        open('left.txt', 'w'),
        open('right.txt', 'w'),
    ]
    for i in range(0, len(data_buffer), 8):
        # Extract 3 bytes for each channel and convert them to 24-bit signed integers
        left  = (data_buffer[i]       | (data_buffer[i + 1]  << 8) | (data_buffer[i + 2]  << 16)) 
        right = (data_buffer[i + 4]   | (data_buffer[i + 5]  << 8) | (data_buffer[i + 6]  << 16))
        if left & 0x800000:
            left -= 0x1000000
        if right & 0x800000:
            right -= 0x1000000
        # Write the values to respective files
        files[0].write(f"{left}\n")
        files[1].write(f"{right}\n")
        # Optional: Flush files to ensure data is written immediately
        for f in files:
            f.flush()
    return None
def write_tdm4(data_buffer):
    # File handles for each channel
    files = [
        open('slot1.txt', 'w'),
        open('slot2.txt', 'w'),
        open('slot3.txt', 'w'),
        open('slot4.txt', 'w'),
    ]
    for i in range(0, len(data_buffer), 16):
        # Extract 3 bytes for each channel and convert them to 24-bit signed integers
        slot1 = (data_buffer[i]          | (data_buffer[i + 1]   << 8) | (data_buffer[i +  2]  << 16)) 
        slot2 = (data_buffer[i +  4]     | (data_buffer[i + 5]   << 8) | (data_buffer[i +  6]  << 16))
        slot3 = (data_buffer[i +  8]     | (data_buffer[i + 9]   << 8) | (data_buffer[i + 10]  << 16)) 
        slot4 = (data_buffer[i + 12]     | (data_buffer[i + 13]  << 8) | (data_buffer[i + 14]  << 16))
        if slot1 & 0x800000:
            slot1 -= 0x1000000
        if slot2 & 0x800000:
            slot2 -= 0x1000000
        if slot3 & 0x800000:
            slot3 -= 0x1000000
        if slot4 & 0x800000:
            slot4 -= 0x1000000
        # Write the values to respective files
        files[0].write(f"{slot1}\n")
        files[1].write(f"{slot2}\n")
        files[2].write(f"{slot3}\n")
        files[3].write(f"{slot4}\n")
        # Optional: Flush files to ensure data is written immediately
        for f in files:
            f.flush()
    return None
def write_sigle(data_buffer):
    output_file = "single.txt"
    # Open the output file in write mode
    with open(output_file, 'w') as file:
        # Process the received data in 2-byte chunks
        for i in range(0, len(data_buffer), 2):
            # MSB is the first byte, LSB is the second byte
            value = data_buffer[i]| (data_buffer[i + 1] << 8)
            # Write the integer value to the file
            file.write(f"{value}\n")
def read_args():
    # Create the argument parser
    parser = argparse.ArgumentParser(description="Serial communication argument parser")
    
  

    # Add arguments for COM port, baud rate, and sample size
    parser.add_argument("com_port", help="The COM port for the serial connection (e.g., COM3, /dev/ttyUSB0)")
    parser.add_argument("baud_rate", type=int, help="The baud rate for the serial connection (e.g., 9600, 115200)")
    parser.add_argument("sample_size", type=int, help="The number of samples to read") 
    
    args = parser.parse_args()    
    
    return (args.com_port, args.baud_rate, args.sample_size) 
def main():
    com_port, baud_rate, sample_size = read_args()
    
    # Display args
    print(f"COM Port: {com_port}")
    print(f"Baud Rate: {baud_rate}")
    print(f"Sample Size: {sample_size}")
    
    # initialise a port
    ser = serial_port_init(com_port, baud_rate, 100)
    if ser:
        print("Starting...............................")

        # acquire adc data
        print("Reading from built-in ADC")
        ser.write("ADC".encode("utf-8"))
        time.sleep(5)
        print("Ready!!!!!")
        buf = read_from_serial(ser, sample_size*2)
        write_sigle(buf)
        print("Done reading MCU ADC")
        
        # acquire pcm1808 data
        print("Reading from PCM1808")
        ser.write("I2S".encode("utf-8"))
        time.sleep(5)
        print("Ready!!!!!")
        buf = read_from_serial(ser, sample_size*8)
        write_stereo(buf)
        print("Done reading PCM1808")
        
        # acquire ADAU1978 data
        print("Reading from ADAU1978")
        ser.write("TDM".encode("utf-8"))
        time.sleep(5)
        print("Ready!!!!!")
        buf = read_from_serial(ser, sample_size*16)
        write_tdm4(buf)
        print("Done reading ADAU1978")
        
        
        print("Done...............................")
if __name__ == "__main__":
    main()

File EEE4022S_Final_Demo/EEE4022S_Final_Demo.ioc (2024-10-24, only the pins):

Mcu.UserName=STM32F767ZITx
PA11.Signal=USB_OTG_FS_DM
PA12.Signal=USB_OTG_FS_DP
PA3.Signal=GPIO_Output
PB0.GPIO_Label=LD1
PB0.Signal=GPIO_Output
PB14.GPIO_Label=LD3
PB14.Signal=GPIO_Output
PB7.GPIO_Label=LD2
PB7.Signal=GPIO_Output
PB8.Signal=I2C1_SCL
PB9.Signal=I2C1_SDA
PC0.Signal=GPIO_Output
PC13.Signal=GPXTI13
PC14/OSC32_IN.Signal=RCC_OSC32_IN
PC15/OSC32_OUT.Signal=RCC_OSC32_OUT
PC3.Signal=GPIO_Output
PE2.Signal=SAI1_MCLK_A
PE3.Signal=SAI1_SD_B
PE4.Signal=SAI1_FS_A
PE5.Signal=SAI1_SCK_A
PE6.Signal=SAI1_SD_A
PF3.Signal=ADC3_IN9
PF7.Signal=SAI1_MCLK_B
PF8.Signal=SAI1_SCK_B
PF9.Signal=SAI1_FS_B
PH0/OSC_IN.Signal=RCC_OSC_IN
PH1/OSC_OUT.Signal=RCC_OSC_OUT

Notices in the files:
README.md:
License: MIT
